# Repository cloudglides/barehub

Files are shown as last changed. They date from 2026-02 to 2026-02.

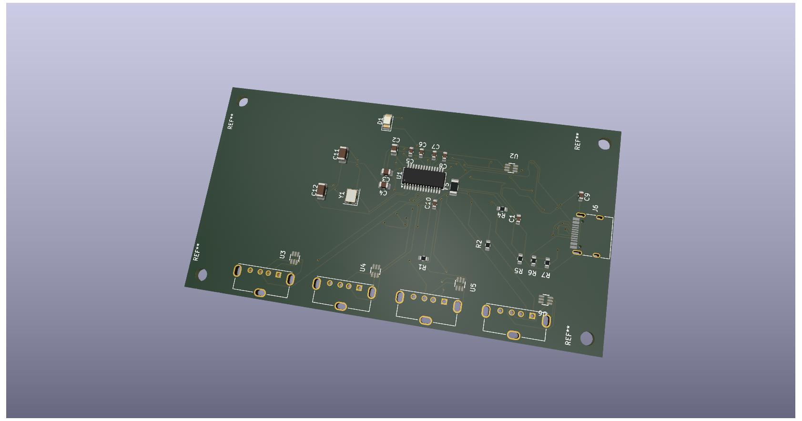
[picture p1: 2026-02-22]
pcb_kicad/barehub.png

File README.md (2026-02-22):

<p align="center">

</p>
<h1 align="center">BAREHUB</h1>

<p align="center">
  <a href="https://www.youtube.com/watch?v=AxE4TltnvjI">BUILD!(not yet) • </a>
 <a href="https://cad.onshape.com/documents/4b9bd96242774528e3dbc81e/w/aa711833ecff2e684d7276d3/e/eb8acac42691808165e34fed">Onshape timeline</a>
</p>

<p align="center">
   A very very cool minimal USB hub featuring 1 USB-C in, 4 USB-A out, small PCB, fast USB 2.0.
</p>

<details>
<summary><strong>3D Case</strong></summary>

<br>

<p align="center">
  
</p>

<p align="center">
  
</p>

<p align="center">
  
</p>

</details>

<br>

<details>
<summary><strong>PCB / Schematic</strong></summary>

<br>

<p align="center">
  
</p>

<br>

<p align="center">
  
</p>

</details>

<br>

<details>
<summary><strong>Build Instructions</strong></summary>

<br>

<p>
  To assemble the BAREHUB PCB:
</p>

<ol>
  <li>Apply solder paste to the pads of the PCB.</li>
  <li>Place all components (FE1.1S IC, USB ports, capacitors, etc.) onto their pads.</li>
  <li>Use a hotplate(reccomended) or hot-air gun to reflow the solder paste and solder components down.</li>
  <li>Inspect solder joints and touch up any misaligned components(dont burn em duh) if needed.</li>
</ol>

</details>

<br>

<details>
<summary><strong>License</strong></summary>

<br>

<p>
This project is licensed under a <b>Creative Commons Attribution-NonCommercial-ShareAlike style license with commercial permission</b>:
</p>

<ul>
  <li>You are free to copy, modify, and sell products based on this design.</li>
  <li>You <b>must credit "BAREHUB by cloudglides"</b> wherever the design is used.</li>
  <li>Derivatives are allowed and can be sold, but attribution is required.</li>
</ul>

<p>
In short: <b>copy, earn, remix, but always credit the original creator.</b>
</p>

</details>

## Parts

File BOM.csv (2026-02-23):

Item | Quantity | Source | Unit Price (INR) | Unit Price (USD) | Total Price (INR) | Total Price (USD)
FE1.1s | 2x | https://robu.in/product/fe1-1s-bsop28bcn-terminus-tech-ssop-28-150mil-usb-converters-rohs/ | 100 | 1.1111 | 200 | 2.2222
SMF05CT1G | 15x | https://robu.in/product/smf05ct1g-onsemi-smf05ct1g-tvs-diode-smf-unidirectional-5-v-12-5-v-sc-88-6-pins/ | 12 | 0.1333 | 180 | 2
USB-C Female 16P SMD | 3x | https://robu.in/product/type-c-31-m-12-hroparts-5a-1-16p-female-type-c-smd-usb-connectors-rohs/ | 38 | 0.4222 | 114 | 1.2667
12MHz SMD Crystal | 5x | https://robu.in/product/12mhz-smd-crystal/ | 10 | 0.1111 | 50 | 0.5556
USB-A Female | 14x | https://robu.in/product/u221-041n-1bz57-s1-xkb-usb-2-0-direct-insert-female-usb-connectors-rohs/ | 6 | 0.0667 | 84 | 0.9333
2.7k ohm Resistor 1% 0603 | 20x | https://robu.in/product/rt0603fre072k7l-yageo-100mw-thin-film-resistor/ | 1.85 | 0.0206 | 37 | 0.4111
10k ohm Resistor 0603 | 20x | https://robu.in/product/rt0603fre1010kl-yageo-0-1w-thin-film-resistor/ | 1.36 | 0.0151 | 27.2 | 0.3022
5.1k ohm Resistor 0603 | 20x | https://robu.in/product/ac0603fr-135k1l-yageo-0-1w-thick-film-resistors/ | 0.94 | 0.0104 | 18.8 | 0.2089
330 ohm Resistor 0603 | 10x | https://robu.in/product/0603waf3300t5e-uniohm-royal-ohm-100mw-thick-film-resistors-75v/ | 0.08 | 0.0009 | 0.8 | 0.0089
0.1uF Capacitor 0603 | 30x | https://robu.in/product/tcc0603x7r104k101ct-cctc-0-1uf-100v-ceramic-capacitor/ | 0.23 | 0.0026 | 6.9 | 0.0767
10uF Capacitor 0603 | 25x | https://robu.in/product/tcc0603x5r106k6r3ct-cctc-smt-ceramic-capacitors/ | 0.35 | 0.0039 | 8.75 | 0.0972
4.7uF Capacitor 0603 | 20x | https://robu.in/product/tcc0603x7r475k6r3ct-cctc-smt-ceramic-capacitors/ | 0.58 | 0.0064 | 11.6 | 0.1289
22pF Capacitor 0603 | 20x | https://robu.in/product/22pf-0603-surface-mount-multilayer-ceramic-capacitor-pack-of-50/ | 3.14 | 0.0349 | 62.8 | 0.6978
Red LED 0603 (Everlight 19-217/R6C) | 20x | https://robu.in/product/19-217-r6c-p1q2-3t-everlight-red-624nm-led-indication-discrete-2v-0603-1608-metric/ | 3 | 0.0333 | 60 | 0.6667
Polyfuse 500mA 1206 (0ZCJ0050AF2E) | 20x | https://robu.in/product/0zcj0050af2e-bel-fuse-circuit-protection/ | 3.29 | 0.0366 | 65.8 | 0.7311
PCB (5x, LionCircuits) | 1x (5 PCBs) | https://www.lioncircuits.com/quote | 1286 | 14.2889 | 1286 | 14.2889
3D Printed Case | 1x | print legion | 580 | 6.4444 | 580 | 6.4444
TOTAL |  |  |  |  | 2793.65 | 31.0406 | ~32$

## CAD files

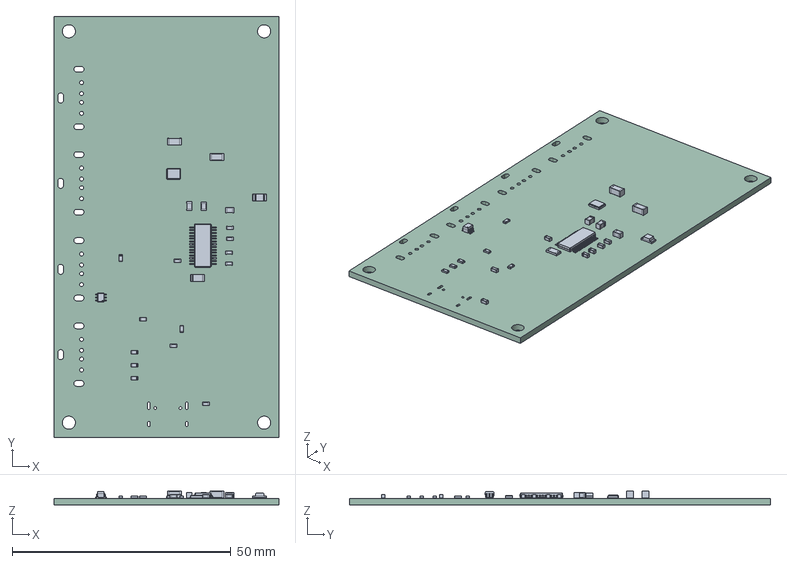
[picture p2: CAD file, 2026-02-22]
case_3d/barehub.step
51.4 x 96.2 x 3.20 mm
R_0603_1608Metric x 6
C_0603_1608Metric x 7
SSOP-28_3.9x9.9mm_P0.635mm
LED_1206_3216Metric
Crystal_SMD_3225-4Pin_3.2x2.5mm
C_1206_3216Metric x 2
C_0805_2012Metric x 3
SMF05CT1G
Fuse_1206_3216Metric
barehub_PCB

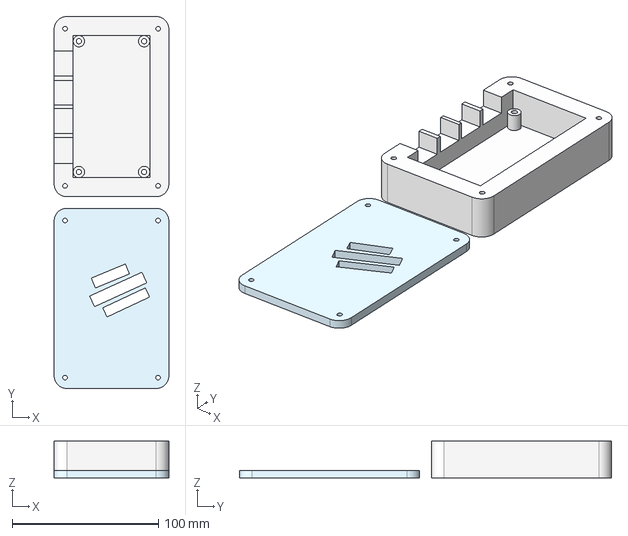
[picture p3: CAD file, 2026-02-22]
pcb_kicad/bare_hub_case.step
78.4 x 254.3 x 25.0 mm

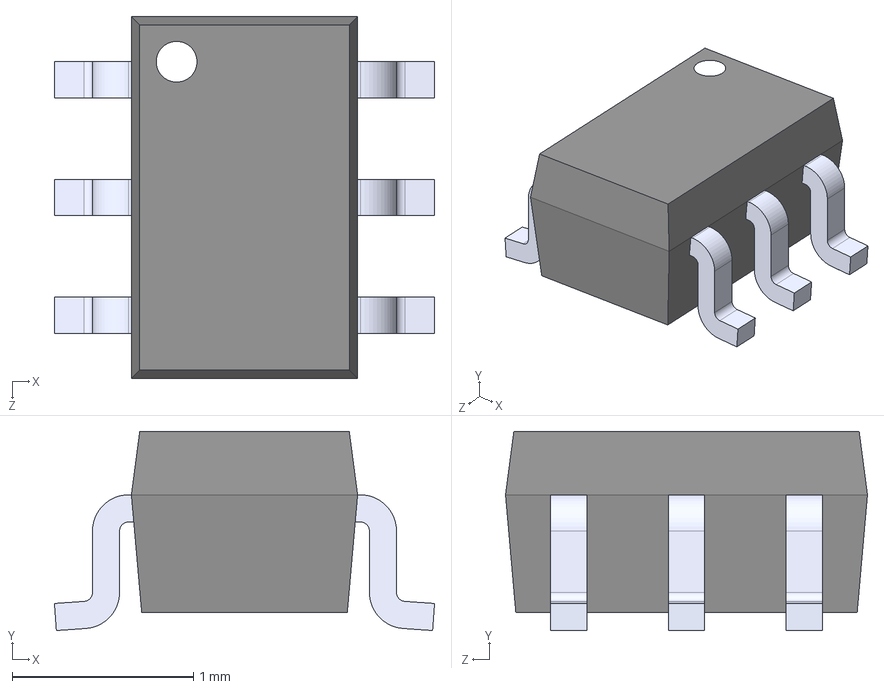
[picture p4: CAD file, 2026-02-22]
pcb_kicad/SMF05CT1G/SMF05CT1G.step
2.10 x 1.10 x 2.00 mm

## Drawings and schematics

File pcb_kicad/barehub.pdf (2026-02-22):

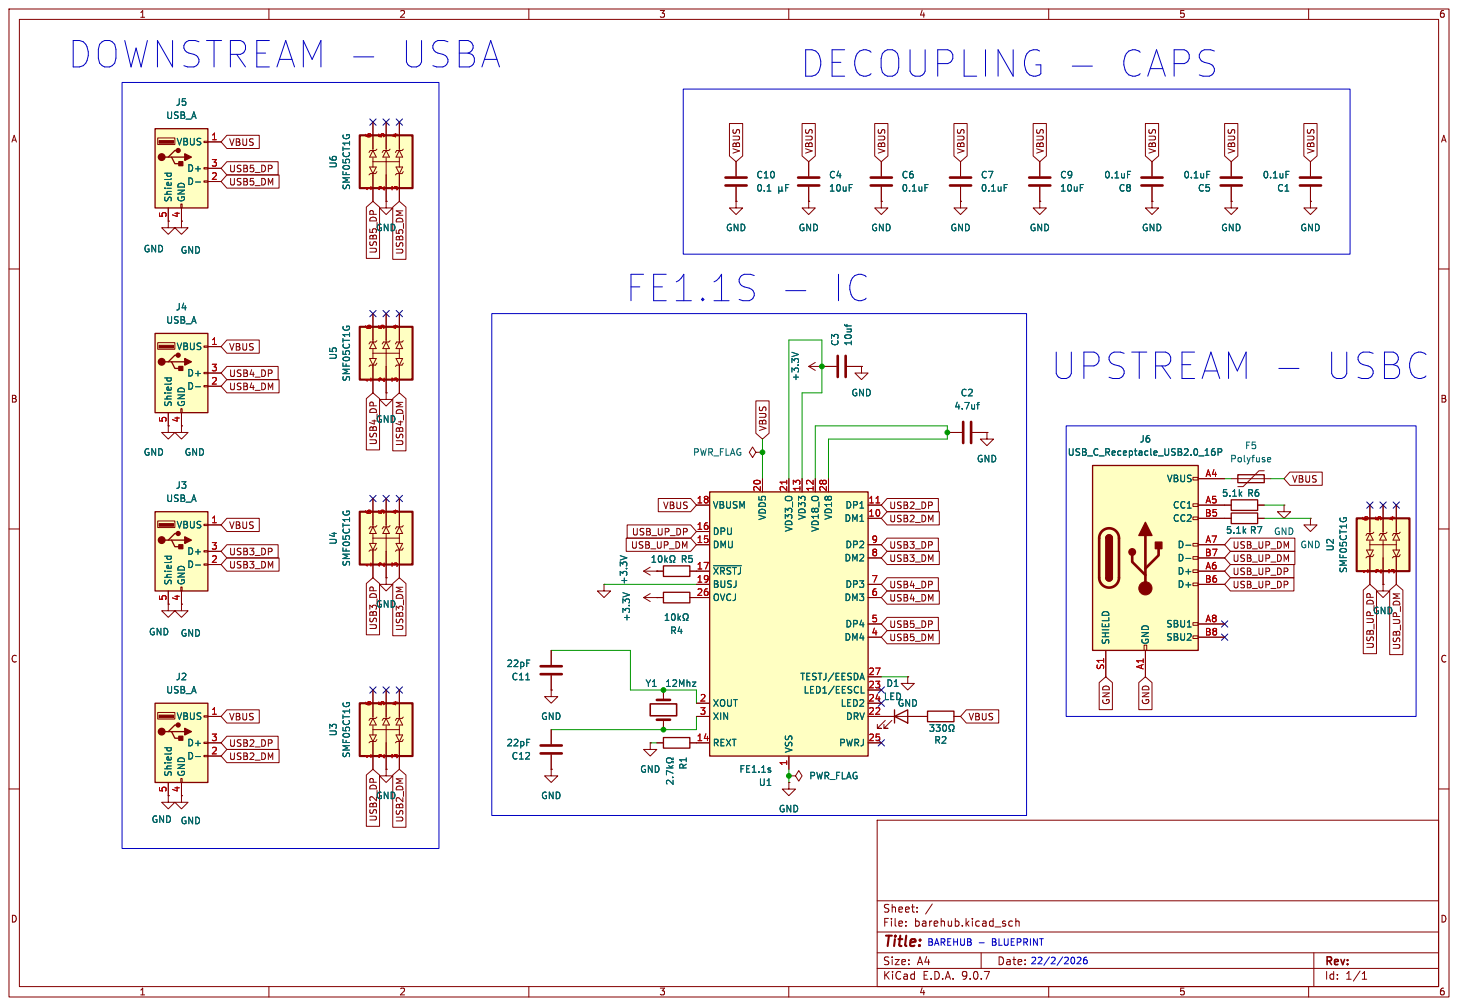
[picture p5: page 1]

4 GND GND GND GND GND

4 U2 SMF05CT1G GND GND SHIELD S1 GND A1 VBUS A4 CC1 A5 CC2 B5 D- A7 D- B7 D+ A6 D+ B6 SBU1 A8 SBU2 B8

4 VBUS 1 D+ 3 D- 2 GND GND GND

Id: 1/1 Title: File: barehub.kicad_sch Sheet: /

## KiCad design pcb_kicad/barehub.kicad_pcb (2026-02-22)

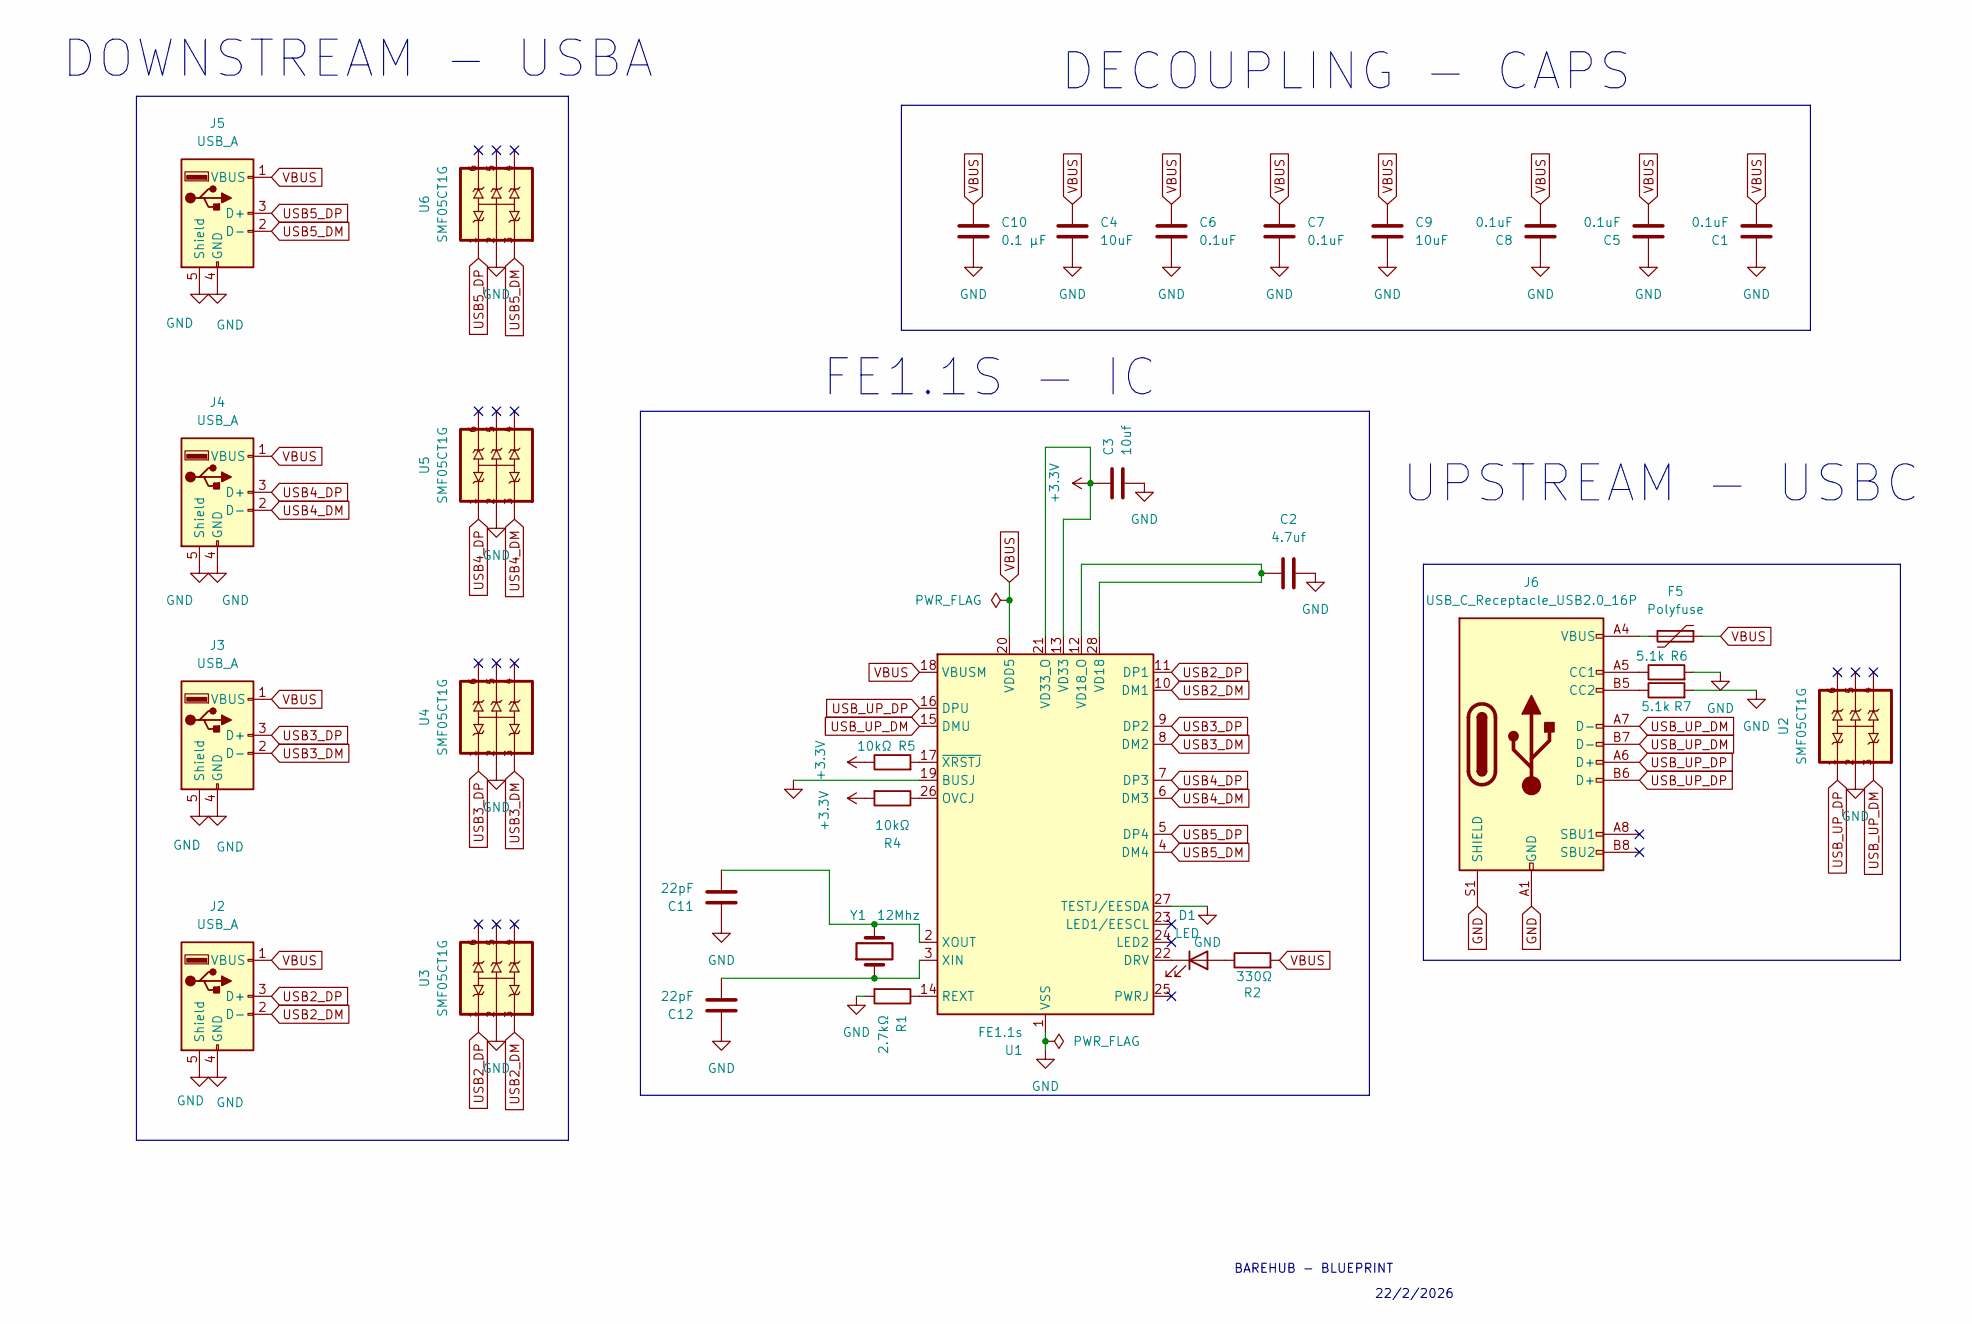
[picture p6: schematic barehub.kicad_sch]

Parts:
C1, C5, C6, C7, C8: 0.1uF; C_0603_1608Metric
C2: 4.7uf; C_0805_2012Metric
C3: 10uf; C_0805_2012Metric
C4: 10uF; C_0805_2012Metric
C9: 10uF; C_0603_1608Metric
C10: 0.1 µF; C_0603_1608Metric
C11, C12: 22pF; C_1206_3216Metric
D1: LED; LED_1206_3216Metric
F5: Polyfuse; Fuse_1206_3216Metric
J2, J3, J4, J5: USB_A; USB_A_Molex_105057_Vertical
J6: USB_C_Receptacle_USB2.0_16P; USB_C_Receptacle_HRO_TYPE-C-31-M-12
R1: 2.7kΩ; R_0603_1608Metric
R2: 330Ω; R_0603_1608Metric
R4, R5: 10kΩ; R_0603_1608Metric
R6, R7: 5.1k; R_0603_1608Metric
U1: FE1.1s; SSOP-28_3.9x9.9mm_P0.635mm
U2, U3, U4, U5, U6: SMF05CT1G; SOT65P210X110-6N
Y1: 12Mhz; Crystal_SMD_3225-4Pin_3.2x2.5mm

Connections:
+3.3V: C3.2, R4.2, R5.1, U1.13 (VD33), U1.21 (VD33_O)
GND: C1.1, C2.2, C3.1, C4.2, C5.1, C6.2, C7.2, C8.1, C9.2, C10.2, C11.1, C12.1, J2.4 (GND), J2.5 (Shield), J3.4 (GND), J3.5 (Shield), J4.4 (GND), J4.5 (Shield), J5.4 (GND), J5.5 (Shield), J6.A1 (GND), J6.A12 (GND), J6.B1 (GND), J6.B12 (GND), J6.S1 (SHIELD), R1.2, R6.2, R7.2, U1.1 (VSS), U1.19 (BUSJ), U1.27 (TESTJ/EESDA), U2.2, U3.2, U4.2, U5.2, U6.2
unnamed: D1.2 (A), R2.1
unnamed: D1.1 (K), U1.22 (DRV)
unnamed: F5.2, J6.A4 (VBUS), J6.A9 (VBUS), J6.B4 (VBUS), J6.B9 (VBUS)
unnamed: J6.A5 (CC1), R6.1
unnamed: J6.B5 (CC2), R7.1
unnamed: R4.1, U1.26 (OVCJ)
unnamed: R1.1, U1.14 (REXT)
unnamed: C2.1, U1.12 (VD18_O), U1.28 (VD18)
unnamed: C12.2, U1.3 (XIN), Y1.1
unnamed: C11.2, U1.2 (XOUT), Y1.2
unnamed: R5.2, U1.17 (~XRSTJ)
USB2_DM: J2.2 (D-), U1.10 (DM1), U3.3
USB2_DP: J2.3 (D+), U1.11 (DP1), U3.1
USB3_DM: J3.2 (D-), U1.8 (DM2), U4.3
USB3_DP: J3.3 (D+), U1.9 (DP2), U4.1
USB4_DM: J4.2 (D-), U1.6 (DM3), U5.3
USB4_DP: J4.3 (D+), U1.7 (DP3), U5.1
USB5_DM: J5.2 (D-), U1.4 (DM4), U6.3
USB5_DP: J5.3 (D+), U1.5 (DP4), U6.1
USB_UP_DM: J6.A7 (D-), J6.B7 (D-), U1.15 (DMU), U2.3
USB_UP_DP: J6.A6 (D+), J6.B6 (D+), U1.16 (DPU), U2.1
VBUS: C1.2, C4.1, C5.2, C6.1, C7.1, C8.2, C9.1, C10.1, F5.1, J2.1 (VBUS), J3.1 (VBUS), J4.1 (VBUS), J5.1 (VBUS), R2.2, U1.18 (VBUSM), U1.20 (VDD5)

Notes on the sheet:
DECOUPLING - CAPS
FE1.1S - IC
UPSTREAM - USBC
22/2/2026
DOWNSTREAM - USBA
BAREHUB - BLUEPRINT

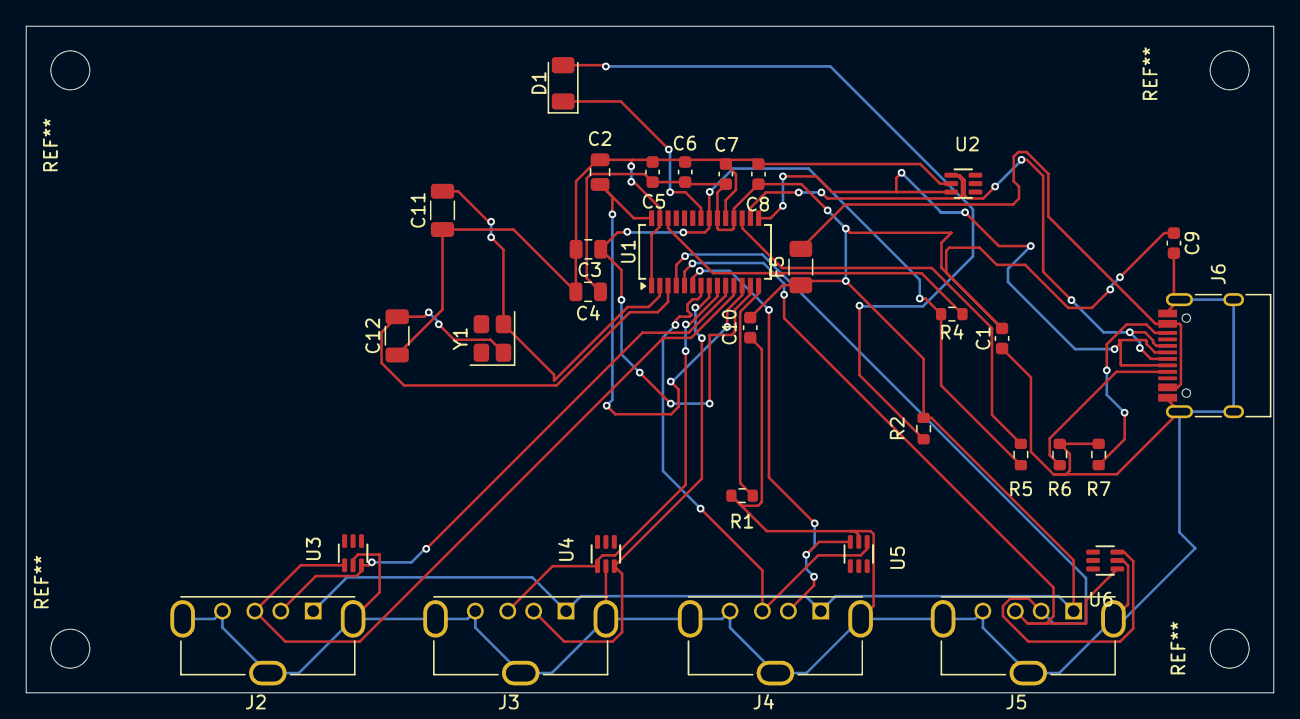
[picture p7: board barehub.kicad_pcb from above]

Board: 2 copper layers, 96.2 x 51.4 mm, 32 parts (0 on the bottom side), 24 nets.

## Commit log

2026-02-22 chore: add BOM
    [barehub.kicad_pcb, barehub.kicad_sch]
2026-02-22 chore: add BOM (opssie)
    [BOM.csv]
2026-02-23 fixes: wrong link
    [BOM.csv]
